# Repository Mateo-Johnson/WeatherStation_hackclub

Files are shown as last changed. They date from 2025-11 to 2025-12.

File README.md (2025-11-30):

# ESP32-C6 All-Inclusive Weather Station

A comprehensive environmental monitoring system designed for autonomous outdoor deployment. This weather station integrates meteorological sensors, air quality monitoring, GPS tracking, and solar power management into a single robust PCB design.

Screenshot 2025-11-29 at 9 49 39 PM
Screenshot 2025-11-29 at 9 50 54 PM
Screenshot 2025-11-29 at 9 50 24 PM
Screenshot 2025-11-29 at 9 52 07 PM

---

## Features

- **Microcontroller:** ESP32-C6-MINI (Wi-Fi 6, Bluetooth 5.2, low-power deep sleep)
- **Environmental Sensors:**
  - BME680: Temperature, Humidity, Pressure, VOC
  - SHT4x: Temperature and Humidity
  - SCD41: CO2, Temperature, Humidity
  - TSL25911: Ambient Light
- **GPS Module:** NEO-M8N with external U.FL antenna
- **Air Quality & Power Monitoring:**
  - Battery voltage, charge state, solar charging support
  - AQI estimation
- **Storage:** MicroSD card (DM3D-SF)
- **Connectivity:** Wi-Fi (primary), LoRa (fallback)
- **Power Management:** Deep sleep with peripheral power gating
- **Security:** TLS for Wi-Fi communications, optional HMAC payload signatures, secure key storage in NVS
- **Optional LEDs:** WS2812B RGB for status indicators

---

## Architecture

The firmware uses an RTOS-based task structure:

| Task | Priority | Description |
|---|---|---|
| SensorTask | High | Wake peripherals, read sensors, push measurements to queues |
| CommsTask | High | Wi-Fi/MQTT/HTTP upload, fallback SD logging, LoRa backup |
| StorageTask | Medium | Buffered SD writes, CRC/JSON formatting |
| PowerManagerTask | Highest  | Sensor power control, deep sleep, battery monitoring |
| WatchdogTask | Low | Detects stuck tasks or I²C bus lock and resets if necessary |

---

## Data Model

```json
{
  "device_id":"mjohnson-weather-v1",
  "timestamp":"2025-11-28T12:52:24Z",
  "sensors": {
    "bme680": {"temp_c": 23.54, "hum_pct": 45.2, "press_hpa": 1013.2, "gas_ohms": 120},
    "sht4x": {"temp_c": 23.50, "hum_pct": 45.1},
    "scd41": {"co2_ppm": 420, "temp_c": 23.4, "rh": 45.0},
    "tsl25911": {"lux": 3200},
    "gps": {"lat": 40.123456, "lon": -73.123456, "fix": true, "hdop": 0.9},
    "battery": {"voltage": 7.40, "charge_pct": 85, "charging": true},
    "aqi_est": 35
  },
  "signature": "xxxxx"  // CRC-8 checksum
}

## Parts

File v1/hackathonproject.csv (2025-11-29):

Reference | Qty | Value | DNP | Exclude from BOM | Exclude from Board | Footprint | Datasheet
BT1 | 1 | Battery_Cell |  |  |  | Battery:BatteryHolder_Keystone_3000_1x12mm | ~
C1,C2,C3,C4,C5,C6,C10,C12,C13,C15,C16,C17,C18,C19,C20 | 15 | 100nF |  |  |  | 10uF:C0402 | ~
C7,C9 | 2 | 10uF |  |  |  | 10uF:C0402 | ~
C8 | 1 | 22uF |  |  |  | 10uF:C0402 | ~
C11 | 1 | 4.7u |  |  |  | RP2350_80QFN_minimal:C_0402_1005Metric_small_pads | ~
C14 | 1 | 470nF |  |  |  | Capacitor_SMD:C_0402_1005Metric | ~
Card1 | 1 | DM3D-SF |  |  |  | DM3D:TF-SMD_DM3D-SF
D1,D2,D3 | 3 | LTST-C150RKT |  |  |  | LED_SMD:LED_1206_3216Metric | ~
D4,D5,D6 | 3 | WS2812B |  |  |  | LED_SMD:LED_WS2812B_PLCC4_5.0x5.0mm_P3.2mm | https://cdn-shop.adafruit.com/datasheets/WS2812B.pdf
J1 | 1 | USB_C_Receptacle_USB2.0_16P |  |  |  | Connector_USB:USB_C_Receptacle_HCTL_HC-TYPE-C-16P-01A | https://www.usb.org/sites/default/files/documents/usb_type-c.zip
J2 | 1 | Conn_02x05_Odd_Even |  |  |  | Connector_PinHeader_2.54mm:PinHeader_2x05_P2.54mm_Vertical | ~
J3 | 1 | U.FL-R-SMT(10) |  |  |  | Connector_Coaxial:U.FL_Hirose_U.FL-R-SMT-1_Vertical | ~
J4 | 1 | Conn_01x03_Pin |  |  |  | Connector_PinHeader_2.54mm:PinHeader_1x03_P2.54mm_Vertical | ~
J5 | 1 | Conn_01x02_Pin |  |  |  | Connector_JST:JST_PH_S2B-PH-K_1x02_P2.00mm_Horizontal | ~
R1,R2,R3,R5,R6,R7,R10,R11,R12 | 9 | RC0402FR-075K1L (5.1kΩ) |  |  |  | 0402:R0402 | ~
R4,R8,R9 | 3 | RC0402FR-13220RL (220Ω) |  |  |  | 0402:R0402 | ~
R13,R14 | 2 | 10k |  |  |  | 0402:R0402 | ~
SW1,SW2 | 2 | SKRKAGE020 |  |  |  | Button_Switch_SMD:SW_Push_SPST_NO_Alps_SKRK | ~
U1 | 1 | ESP32-C6-MINI-1 |  |  |  | RF_Module:ESP32-C6-MINI-1 | https://www.espressif.com/sites/default/files/documentation/esp32-c6-mini-1_mini-1u_datasheet_en.pdf
U2 | 1 | CH340N |  |  |  | Package_SO:SOP-8_3.9x4.9mm_P1.27mm | https://aitendo3.sakura.ne.jp/aitendo_data/product_img/ic/inteface/CH340N/ch340n.pdf
U3 | 1 | NEO-M8N |  |  |  | RF_GPS:ublox_NEO | https://content.u-blox.com/sites/default/files/NEO-M8-FW3_DataSheet_UBX-15031086.pdf
U4 | 1 | NCP1117-3.3_SOT223 |  |  |  | Package_TO_SOT_SMD:SOT-223-3_TabPin2 | http://www.onsemi.com/pub_link/Collateral/NCP1117-D.PDF
U5 | 1 | DS3231MZ |  |  |  | Package_SO:SOIC-8_3.9x4.9mm_P1.27mm | http://datasheets.maximintegrated.com/en/ds/DS3231M.pdf
U6 | 1 | BME680 |  |  |  | Package_LGA:Bosch_LGA-8_3x3mm_P0.8mm_ClockwisePinNumbering | https://ae-bst.resource.bosch.com/media/_tech/media/datasheets/BST-BME680-DS001.pdf
U7 | 1 | MP2607DL-LF-Z |  |  |  | MP2607DL:MP2607DL
U8 | 1 | SHT4x |  |  |  | Sensor_Humidity:Sensirion_DFN-4_1.5x1.5mm_P0.8mm_SHT4x_NoCentralPad | https://sensirion.com/media/documents/33FD6951/624C4357/Datasheet_SHT4x.pdf
U9 | 1 | SCD41-D-R2 |  |  |  | Sensor:Sensirion_SCD4x-1EP_10.1x10.1mm_P1.25mm_EP4.8x4.8mm | https://sensirion.com/media/documents/E0F04247/631EF271/CD_DS_SCD40_SCD41_Datasheet_D1.pdf
U10 | 1 | TCA9548AMRGER |  |  |  | Package_DFN_QFN:Texas_RGE0024C_VQFN-24-1EP_4x4mm_P0.5mm_EP2.1x2.1mm | http://www.ti.com/lit/ds/symlink/tca9548a.pdf
U11 | 1 | TSL25911FN |  |  |  | OptoDevice:AMS_TSL25911FN | https://ams.com/documents/20143/9331680/TSL2591_DS000338_7-00.pdf

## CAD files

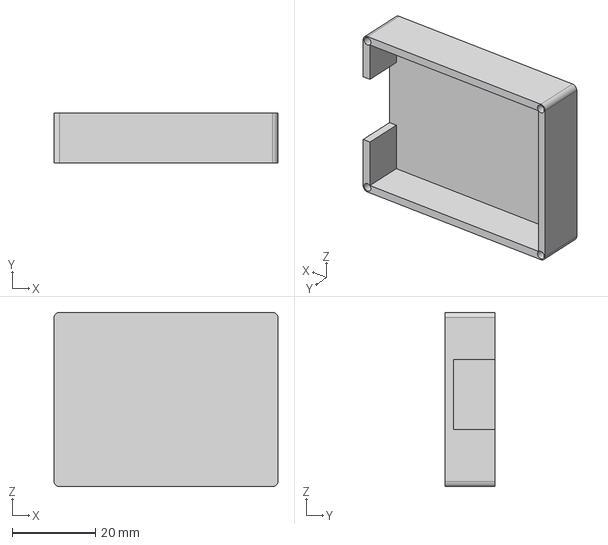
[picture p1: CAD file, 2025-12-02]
v1/case_bottom.step
53.9 x 12.0 x 41.9 mm

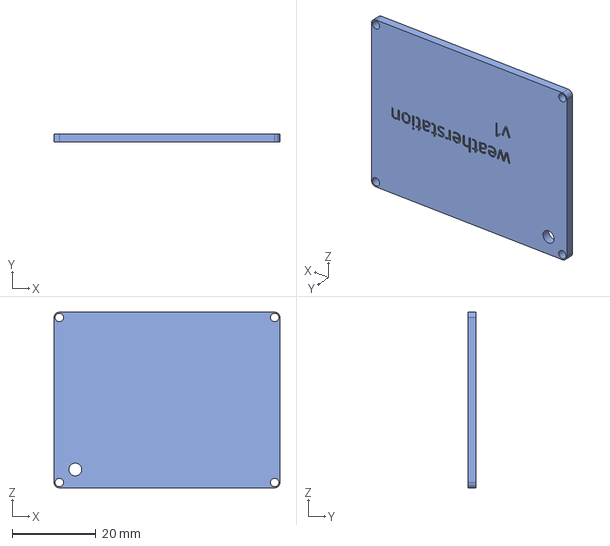
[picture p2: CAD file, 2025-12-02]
v1/case_top.step
53.9 x 2.00 x 41.9 mm

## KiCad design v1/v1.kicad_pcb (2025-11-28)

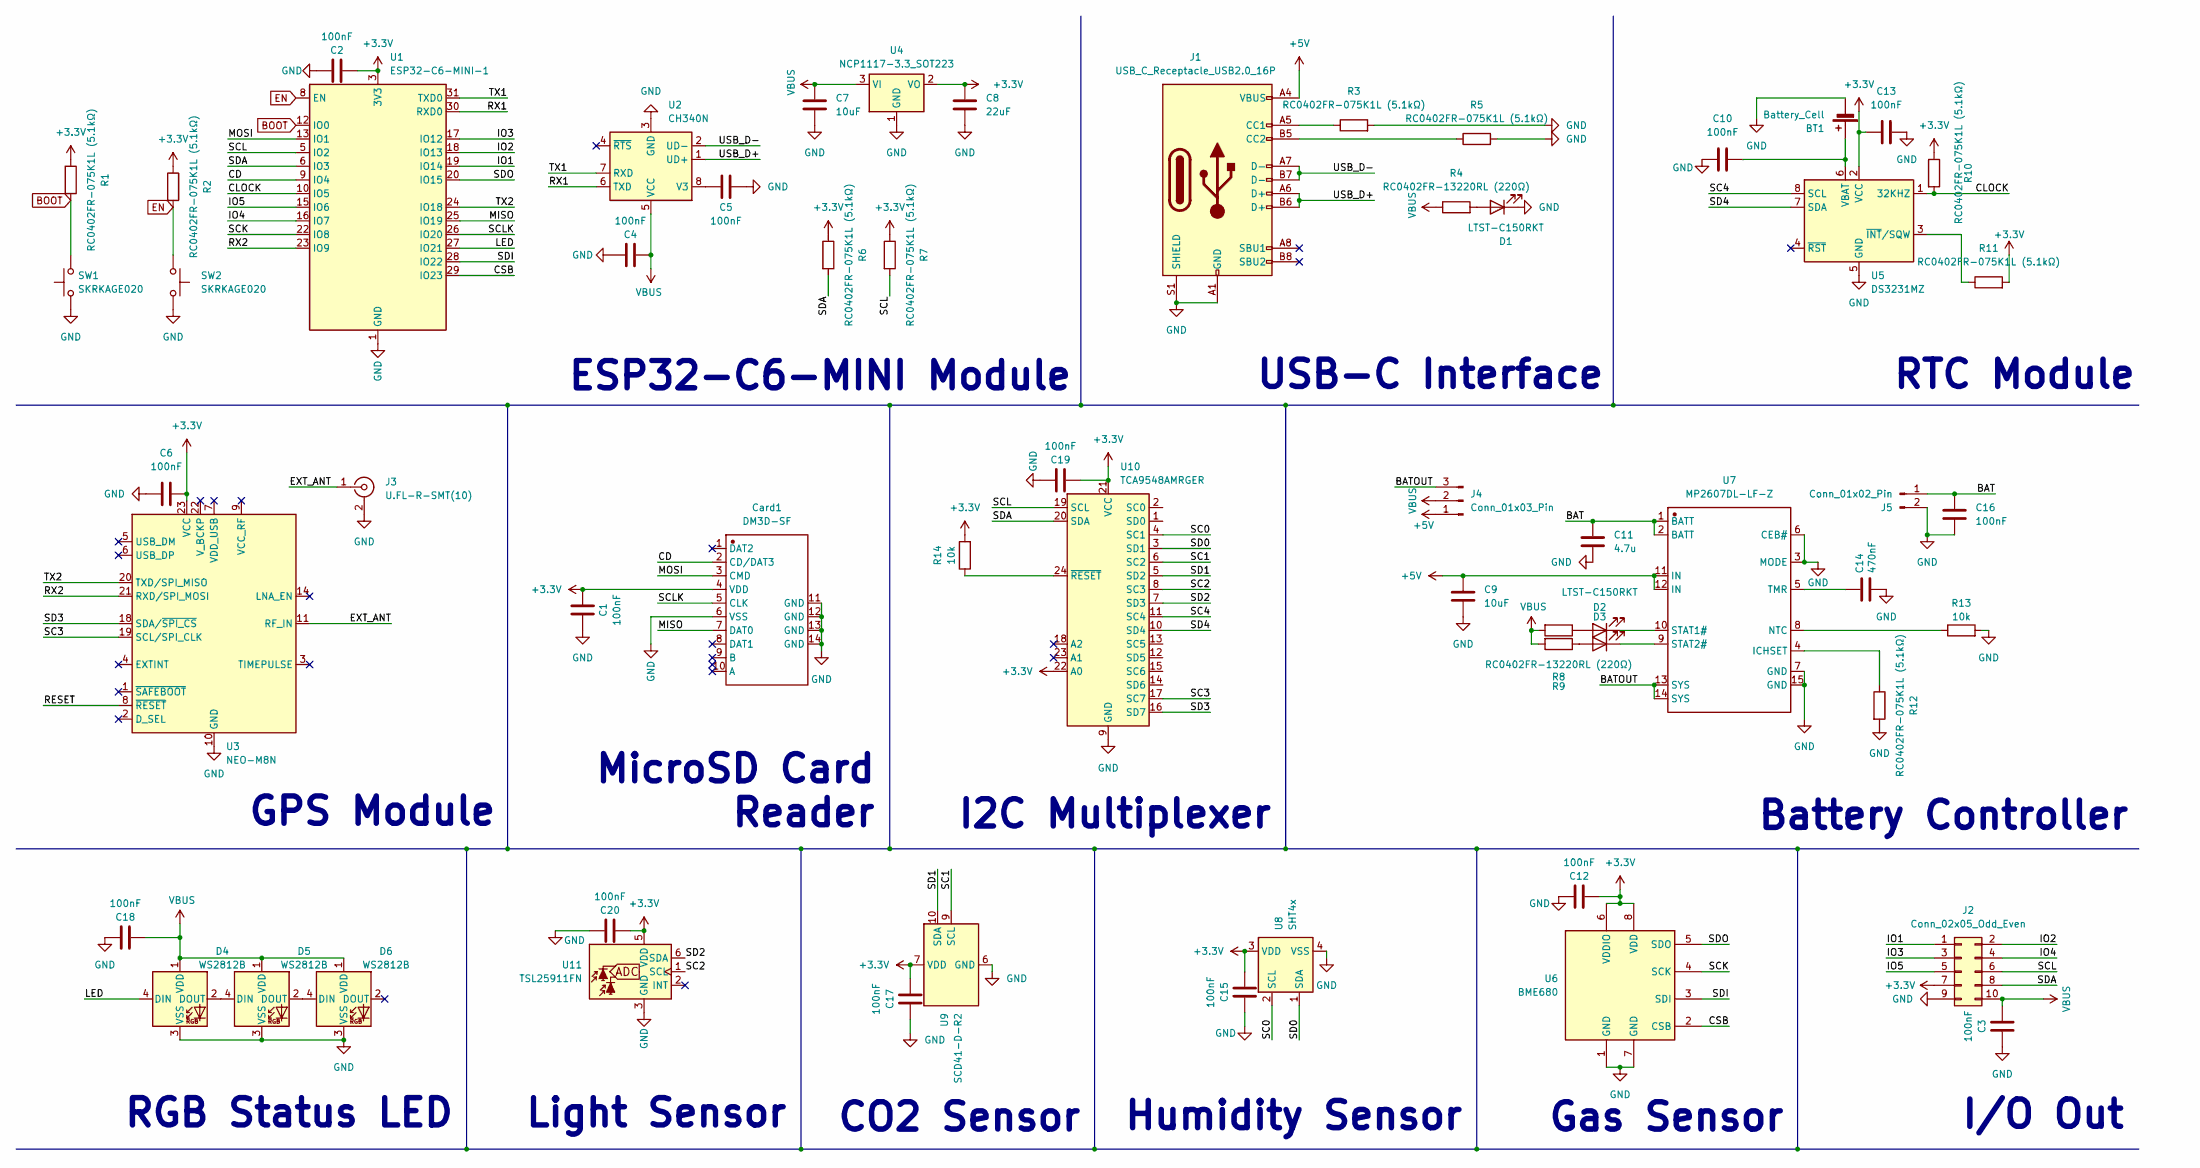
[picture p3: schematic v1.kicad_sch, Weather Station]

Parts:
BT1: Battery_Cell; BatteryHolder_Keystone_3000_1x12mm
C1, C2, C3, C4, C5, C6, C10, C12, C13, C15, C16, C17, C18, C19, C20: 100nF; C0402
C7, C9: 10uF; C0402
C8: 22uF; C0402
C11: 4.7u; C_0402_1005Metric_small_pads
C14: 470nF; C_0402_1005Metric
Card1: DM3D-SF; TF-SMD_DM3D-SF; Manufacturer Part DM3D-SF
D1, D2, D3: LTST-C150RKT; LED_1206_3216Metric
D4, D5, D6: WS2812B; LED_WS2812B_PLCC4_5.0x5.0mm_P3.2mm
J1: USB_C_Receptacle_USB2.0_16P; USB_C_Receptacle_HCTL_HC-TYPE-C-16P-01A
J2: Conn_02x05_Odd_Even; PinHeader_2x05_P2.54mm_Vertical
J3: U.FL-R-SMT(10); U.FL_Hirose_U.FL-R-SMT-1_Vertical
J4: Conn_01x03_Pin; PinHeader_1x03_P2.54mm_Vertical
J5: Conn_01x02_Pin; JST_PH_S2B-PH-K_1x02_P2.00mm_Horizontal
R1, R2, R3, R5, R6, R7, R10, R11, R12: RC0402FR-075K1L (5.1kΩ); R0402
R4, R8, R9: RC0402FR-13220RL (220Ω); R0402
R13, R14: 10k; R0402
SW1, SW2: SKRKAGE020; SW_Push_SPST_NO_Alps_SKRK
U1: ESP32-C6-MINI-1
U2: CH340N; SOP-8_3.9x4.9mm_P1.27mm
U3: NEO-M8N; ublox_NEO
U4: NCP1117-3.3_SOT223; SOT-223-3_TabPin2
U5: DS3231MZ; SOIC-8_3.9x4.9mm_P1.27mm
U6: BME680; Bosch_LGA-8_3x3mm_P0.8mm_ClockwisePinNumbering
U7: MP2607DL-LF-Z; MP2607DL; Manufacturer Part MP2607DL-LF-Z
U8: SHT4x; Sensirion_DFN-4_1.5x1.5mm_P0.8mm_SHT4x_NoCentralPad
U9: SCD41-D-R2; Sensirion_SCD4x-1EP_10.1x10.1mm_P1.25mm_EP4.8x4.8mm
U10: TCA9548AMRGER; Texas_RGE0024C_VQFN-24-1EP_4x4mm_P0.5mm_EP2.1x2.1mm
U11: TSL25911FN; AMS_TSL25911FN

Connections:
+3.3V: C1.1, C2.2, C6.2, C8.1, C12.2, C13.1, C15.2, C17.2, C19.2, C20.2, Card1.4 (VDD), J2.7, R1.1, R2.1, R6.1, R7.1, R10.1, R11.2, R14.2, U1.3 (3V3), U3.23 (VCC), U4.2 (VO), U5.2 (VCC), U6.6 (VDDIO), U6.8 (VDD), U8.3 (VDD), U9.7 (VDD), U9.19 (VDD), U10.21 (VCC), U10.22 (A0), U11.5 (VDD)
+5V: C9.1, J1.A4 (VBUS), J1.A9 (VBUS), J1.B4 (VBUS), J1.B9 (VBUS), J4.1, U7.11 (IN), U7.12 (IN)
/BAT: C11.1, C16.1, J5.1, U7.1 (BATT), U7.2 (BATT)
/BATOUT: J4.3, U7.13 (SYS), U7.14 (SYS)
/CD: Card1.2 (CD/DAT3), U1.9 (IO4)
/CLOCK: R10.2, U1.10 (IO5), U5.1 (32KHZ)
/CSB: U1.29 (IO23), U6.2 (CSB)
/EXT_ANT: J3.1 (In), U3.11 (RF_IN)
/IO1: J2.1, U1.19 (IO14)
/IO2: J2.2, U1.18 (IO13)
/IO3: J2.3, U1.17 (IO12)
/IO4: J2.4, U1.16 (IO7)
/IO5: J2.5, U1.15 (IO6)
/LED: D4.4 (DIN), U1.27 (IO21)
/MISO: Card1.7 (DAT0), U1.25 (IO19)
/MOSI: Card1.3 (CMD), U1.13 (IO1)
/RESET: U3.8 (~RESET)
/RX1: U1.30 (RXD0), U2.6 (TXD)
/RX2: U1.23 (IO9), U3.21 (RXD/SPI_MOSI)
/SC0: U8.2 (SCL), U10.4 (SC1)
/SC1: U9.9 (SCL), U10.6 (SC2)
/SC2: U10.8 (SC3), U11.1 (SCL)
/SC3: U3.19 (SCL/SPI_CLK), U10.17 (SC7)
/SC4: U5.8 (SCL), U10.11 (SC4)
/SCK: U1.22 (IO8), U6.4 (SCK)
/SCL: J2.6, R7.2, U1.5 (IO2), U10.19 (SCL)
/SCLK: Card1.5 (CLK), U1.26 (IO20)
/SD0: U8.1 (SDA), U10.3 (SD1)
/SD1: U9.10 (SDA), U10.5 (SD2)
/SD2: U10.7 (SD3), U11.6 (SDA)
/SD3: U3.18 (SDA/~SPI_CS), U10.16 (SD7)
/SD4: U5.7 (SDA), U10.10 (SD4)
/SDA: J2.8, R6.2, U1.6 (IO3), U10.20 (SDA)
/SDI: U1.28 (IO22), U6.3 (SDI)
/SDO: U1.20 (IO15), U6.5 (SDO)
/TX1: U1.31 (TXD0), U2.7 (RXD)
/TX2: U1.24 (IO18), U3.20 (TXD/SPI_MISO)
/USB_D+: J1.A6 (D+), J1.B6 (D+), U2.1 (UD+)
/USB_D-: J1.A7 (D-), J1.B7 (D-), U2.2 (UD-)
BOOT: R1.2, SW1.2, U1.12 (IO0)
EN: R2.2, SW2.1, U1.8 (EN)
GND: BT1.2 (-), C1.2, C2.1, C3.1, C4.1, C5.1, C6.1, C7.2, C8.2, C9.2, C10.2, C11.2, C12.1, C13.2, C14.2, C15.1, C16.2, C17.1, C18.1, C19.1, C20.1, Card1.6 (VSS), Card1.11 (GND), Card1.12 (GND), Card1.13 (GND), Card1.14 (GND), D1.1 (K), D4.3 (VSS), D5.3 (VSS), D6.3 (VSS), J1.A1 (GND), J1.A12 (GND), J1.B1 (GND), J1.B12 (GND), J1.S1 (SHIELD), J2.9, J3.2 (Ext), J5.2, R3.2, R5.2, R12.2, R13.2, SW1.1, SW2.2, U1.1 (GND), U1.2 (GND), U1.11 (GND), U1.14 (GND), U1.36 (GND), U1.37 (GND), U1.38 (GND), U1.39 (GND), U1.40 (GND), U1.41 (GND), U1.42 (GND), U1.43 (GND), U1.44 (GND), U1.45 (GND), U1.46 (GND), U1.47 (GND), U1.48 (GND), U1.49 (GND), U1.50 (GND), U1.51 (GND), U1.52 (GND), U1.53 (GND), U2.3 (GND), U3.10 (GND), U3.12 (GND), U3.13 (GND), U3.24 (GND), U4.1 (GND), U5.5 (GND), U6.1 (GND), U6.7 (GND), U7.3 (MODE), U7.6 (CEB#), U7.7 (GND), U7.15 (GND), U8.4 (VSS), U9.6 (GND), U9.20 (GND), U9.21 (GND), U10.9 (GND), U11.3 (GND)
unnamed: BT1.1 (+), C10.1, U5.6 (VBAT)
unnamed: D1.2 (A), R4.2
unnamed: D2.2 (A), R8.1
unnamed: D2.1 (K), U7.10 (STAT1#)
unnamed: D3.2 (A), R9.1
unnamed: D3.1 (K), U7.9 (STAT2#)
unnamed: D4.2 (DOUT), D5.4 (DIN)
unnamed: D5.2 (DOUT), D6.4 (DIN)
unnamed: J1.A5 (CC1), R3.1
unnamed: J1.B5 (CC2), R5.1
unnamed: C5.2, U2.8 (V3)
unnamed: R11.1, U5.3 (~INT/SQW)
unnamed: R12.1, U7.4 (ICHSET)
unnamed: R13.1, U7.8 (NTC)
unnamed: C14.1, U7.5 (TMR)
unnamed: R14.1, U10.24 (~RESET)
VBUS: C3.2, C4.2, C7.1, C18.2, D4.1 (VDD), D5.1 (VDD), D6.1 (VDD), J2.10, J4.2, R4.1, R8.2, R9.2, U2.5 (VCC), U4.3 (VI)

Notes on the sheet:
Light Sensor
Battery Controller
RGB Status LED
MicroSD Card Reader
CO2 Sensor
RTC Module
I/O Out
I2C Multiplexer
ESP32-C6-MINI Module
GPS Module
USB-C Interface
Gas Sensor
Humidity Sensor

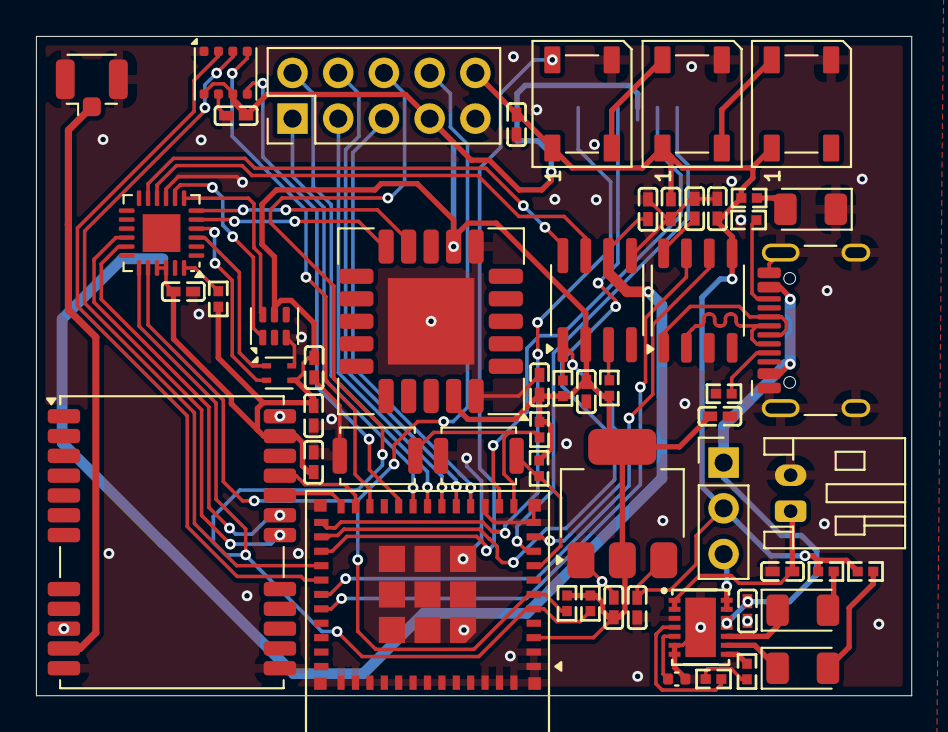
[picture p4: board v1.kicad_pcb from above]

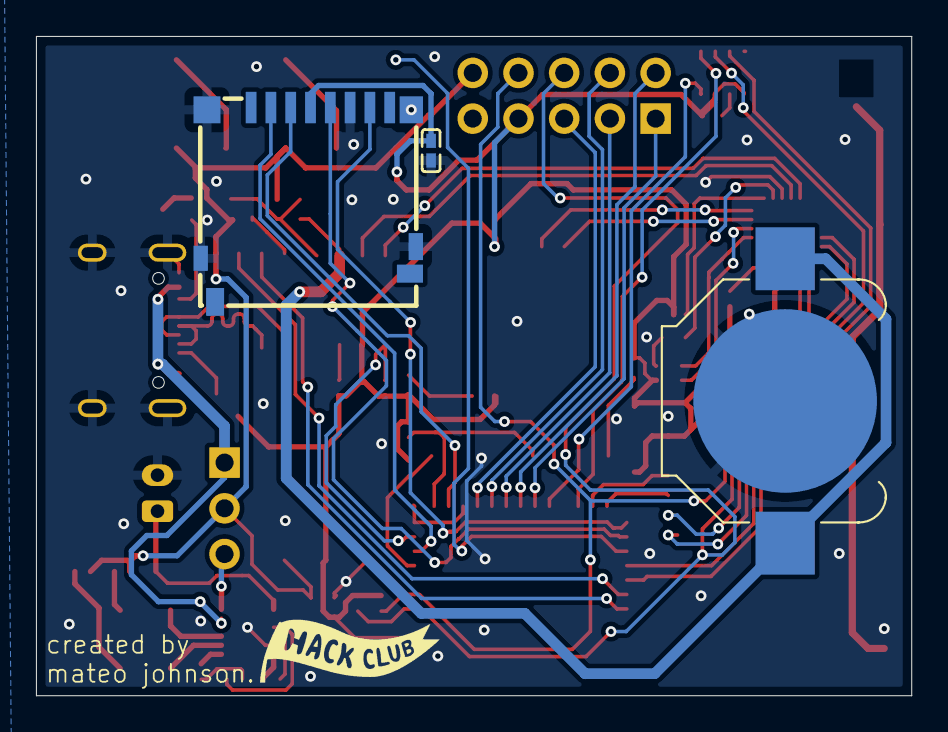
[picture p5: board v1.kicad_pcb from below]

Board: 2 copper layers, 48.6 x 36.6 mm, 59 parts (3 on the bottom side), 58 nets.

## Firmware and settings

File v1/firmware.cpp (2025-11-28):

// firmware_sample.cpp
// Full example C++ firmware skeleton for ESP32-C6 (ESP-IDF) + FreeRTOS.
// This is an implementation-ready sample skeleton demonstrating architecture,
// tasks, queues, recovery, I2C recovery, SD atomic writes, Wi-Fi -> HTTP fallback,
// LoRa fallback, power management and deep-sleep integration.
//
// NOT a drop-in production firmware: sensor drivers, real crypto, and OTA implementation
// must be filled with vendor libraries. This file demonstrates structure, error handling,
// and necessary safety patterns you asked for.
//
// Build with ESP-IDF C++ support. Link with mbedtls, fatfs, vfs, nvs_flash, esp_wifi, tcpip_adapter, etc.
// Keep this as a single-file starting point and extract to modules in real project.

#include <cstdio>
#include <cstring>
#include <cstdint>
#include <cstdlib>

extern "C" {
#include "freertos/FreeRTOS.h"
#include "freertos/task.h"
#include "freertos/queue.h"
#include "freertos/semphr.h"
#include "esp_system.h"
#include "esp_event.h"
#include "nvs_flash.h"
#include "esp_log.h"
#include "driver/i2c.h"
#include "driver/adc.h"
#include "esp_sleep.h"
#include "esp_vfs_fat.h"
#include "sdmmc_cmd.h"
#include "esp_wifi.h"
#include "esp_http_client.h"
#include "esp_ota_ops.h"
}

static const char *TAG = "weather-fw";

/////////////////////////////
// Configuration constants //
/////////////////////////////

static constexpr uint32_t SAMPLE_INTERVAL_SECONDS = 300;         // 5 minutes
static constexpr int MAX_RETRIES = 3;
static constexpr size_t SD_BUFFER_SIZE = 5120;                   // flush threshold
static constexpr int WIFI_CONNECT_TIMEOUT_MS = 10000;
static constexpr int LORA_TX_RETRY = 2;
static constexpr const char *DEVICE_ID = "mjohnson-weather-v1";
static constexpr int I2C_MASTER_PORT = I2C_NUM_0;
static constexpr int I2C_FREQ_HZ = 400000;
static constexpr gpio_num_t PIN_SENSOR_POWER = GPIO_NUM_21;      // example
static constexpr gpio_num_t PIN_GPS_POWER = GPIO_NUM_22;
static constexpr gpio_num_t PIN_LED_STATUS = GPIO_NUM_2;
static constexpr float BATTERY_CRITICAL_VOLTAGE = 6.5f;          // example for 2S Li-ion
static constexpr float BATTERY_LOW_WARNING_VOLTAGE = 7.0f;

///////////////////////////
// Data structures/types //
///////////////////////////

struct Bme680Sample { bool present; float temp_c; float hum_pct; float press_hpa; int gas_ohms; };
struct Sht4xSample { bool present; float temp_c; float hum_pct; };
struct Scd41Sample { bool present; int co2_ppm; float temp_c; float rh; };
struct Tsl25911Sample { bool present; float lux; };
struct GpsSample { bool present; double lat; double lon; bool fix; float hdop; uint64_t fix_age_s; };
struct BatterySample { float voltage; int pct; bool charging; };

struct Sample {
    char timestamp[32]; // ISO8601
    Bme680Sample bme680;
    Sht4xSample sht4x;
    Scd41Sample scd41;
    Tsl25911Sample tsl25911;
    GpsSample gps;
    BatterySample battery;
    int aqi_est;
    uint32_t crc8;
};

//////////////////////
// RTOS primitives  //
//////////////////////

static QueueHandle_t g_storage_queue = nullptr;   // Items: Sample*
static QueueHandle_t g_comms_queue = nullptr;     // Items: Sample*
static SemaphoreHandle_t g_i2c_mutex = nullptr;
static SemaphoreHandle_t g_sd_mutex = nullptr;
static TaskHandle_t g_watchdog_handle = nullptr;

//////////////////////////
// Helper / utilities   //
//////////////////////////

static uint32_t compute_crc8(const uint8_t *data, size_t len) {
    // simple CRC-8 (poly 0x07) for illustrative purposes
    uint8_t crc = 0;
    for (size_t i = 0; i < len; ++i) {
        crc ^= data[i];
        for (int b = 0; b < 8; ++b) {
            crc = (crc & 0x80) ? (uint8_t)((crc << 1) ^ 0x07) : (uint8_t)(crc << 1);
        }
    }
    return crc;
}

static void format_timestamp_iso8601(char *out, size_t out_sz) {
    // Attempt to read from RTC or system time.
    time_t now;
    time(&now);
    struct tm timeinfo;
    gmtime_r(&now, &timeinfo);
    strftime(out, out_sz, "%Y-%m-%dT%H:%M:%SZ", &timeinfo);
}

////////////////////////////
// Peripheral init stubs  //
////////////////////////////

static esp_err_t init_nvs_and_rtc() {
    esp_err_t err = nvs_flash_init();
    if (err == ESP_ERR_NVS_NO_FREE_PAGES || err == ESP_ERR_NVS_NEW_VERSION_FOUND) {
        ESP_ERROR_CHECK(nvs_flash_erase());
        err = nvs_flash_init();
    }
    if (err != ESP_OK) {
        ESP_LOGE(TAG, "NVS init failed: %d", err);
        return err;
    }
    // RTC assumed via DS3231 hardware; leave driver to implement. Here we verify system time plausibility.
    time_t now;
    time(&now);
    if (now < 1609459200) { // If before 2021-01-01 assume RTC unset
        ESP_LOGW(TAG, "System time not set; will sync later.");
    }
    return ESP_OK;
}

static esp_err_t init_i2c_bus() {
    // Strict initialization order and bus recovery enabled.
    i2c_config_t conf{};
    conf.mode = I2C_MODE_MASTER;
    conf.sda_io_num = (gpio_num_t)18;
    conf.scl_io_num = (gpio_num_t)19;
    conf.sda_pullup_en = GPIO_PULLUP_ENABLE;
    conf.scl_pullup_en = GPIO_PULLUP_ENABLE;
    conf.master.clk_speed = I2C_FREQ_HZ;
    esp_err_t err = i2c_param_config(I2C_MASTER_PORT, &conf);
    if (err != ESP_OK) return err;
    err = i2c_driver_install(I2C_MASTER_PORT, conf.mode, 0, 0, 0);
    if (err != ESP_OK) {
        ESP_LOGE(TAG, "i2c_driver_install failed: %d", err);
        return err;
    }
    return ESP_OK;
}

static void i2c_bus_recover() {
    // Attempt to recover stuck I2C bus: toggle SCL pulses and generate STOP.
    ESP_LOGW(TAG, "Attempting I2C bus recovery...");
    // Implementation depends on pin muxing; simplified here: re-init driver
    i2c_driver_delete(I2C_MASTER_PORT);
    vTaskDelay(pdMS_TO_TICKS(50));
    init_i2c_bus();
    ESP_LOGW(TAG, "I2C re-init attempted.");
}

//////////////////////////
// SD card (atomic append)
//////////////////////////

static const char *SD_MOUNT_POINT = "/sdcard";
static bool sd_mounted = false;

static esp_err_t init_sdcard() {
    esp_err_t ret;
    sdmmc_card_t *card = nullptr;
    esp_vfs_fat_sdmmc_mount_config_t mount_cfg = {
        .format_if_mount_failed = false,
        .max_files = 4,
    };
    // Default to 1-line SDMMC host or SPI host depending on hardware.
    ret = esp_vfs_fat_sdcard_mount(SD_MOUNT_POINT, nullptr, &mount_cfg, &card);
    if (ret == ESP_OK) {
        sd_mounted = true;
        ESP_LOGI(TAG, "SD card mounted at %s", SD_MOUNT_POINT);
        return ESP_OK;
    } else {
        ESP_LOGW(TAG, "Failed to mount SD card (%d). Will retry later.", ret);
        return ret;
    }
}

// Atomic append pattern: write to temp file, fsync, rename to target (append by opening, writing, fsync)
static bool sd_atomic_append_line(const char *filename, const char *line) {
    if (!sd_mounted) return false;
    if (xSemaphoreTake(g_sd_mutex, pdMS_TO_TICKS(2000)) != pdTRUE) {
        ESP_LOGW(TAG, "SD mutex busy");
        return false;
    }
    bool ok = false;
    char tmpname[256];
    snprintf(tmpname, sizeof(tmpname), "%s.tmp", filename);
    FILE *f = fopen(tmpname, "w");
    if (!f) {
        ESP_LOGE(TAG, "Failed to open tmp file for SD append");
        goto cleanup;
    }
    if (fprintf(f, "%s\n", line) < 0) goto cleanup_close;
    fflush(f);
    fsync(fileno(f));
    fclose(f);
    f = nullptr;

    // Append tmp to final file atomically by reopening final and appending then removing tmp.
    FILE *final = fopen(filename, "a");
    if (!final) {
        ESP_LOGE(TAG, "Failed to open final SD file for append");
        goto cleanup;
    }
    FILE *tmp = fopen(tmpname, "r");
    if (!tmp) {
        fclose(final);
        goto cleanup;
    }
    char buf[512];
    size_t r;
    while ((r = fread(buf, 1, sizeof(buf), tmp)) > 0) {
        if (fwrite(buf, 1, r, final) != r) {
            fclose(tmp); fclose(final);
            goto cleanup;
        }
    }
    fflush(final);
    fsync(fileno(final));
    fclose(tmp);
    fclose(final);
    remove(tmpname);
    ok = true;
    goto cleanup;

cleanup_close:
    if (f) fclose(f);
cleanup:
    xSemaphoreGive(g_sd_mutex);
    return ok;
}

//////////////////////
// Wi-Fi / HTTP stub //
//////////////////////

static bool wifi_connect_blocking() {
    // Implement a blocking connect with timeout. Here we stub successful connection.
    // In production, start Wi-Fi, wait for IP event or timeout.
    ESP_LOGI(TAG, "Connecting Wi-Fi (stub)...");
    vTaskDelay(pdMS_TO_TICKS(2000)); // simulate
    // return false to simulate offline during testing; return true if connected.
    return true;
}

static bool http_post_json(const char *url, const char *json_payload) {
    // Simplified synchronous HTTP POST. In production use esp_http_client APIs and proper TLS config.
    ESP_LOGI(TAG, "HTTP POST to %s - payload len %d", url, (int)strlen(json_payload));
    vTaskDelay(pdMS_TO_TICKS(300)); // simulate network latency
    // Simulate success
    return true;
}

//////////////////
// LoRa stub    //
//////////////////

static bool lora_send_binary(const uint8_t *data, size_t len) {
    // Stub LoRa transmission via SPI to module; handle ack etc. Return true on success.
    ESP_LOGI(TAG, "LoRa send %zu bytes (stub)", len);
    vTaskDelay(pdMS_TO_TICKS(100));
    return true;
}

//////////////////////////
// Sensor driver stubs  //
//////////////////////////

static Bme680Sample read_bme680() {
    Bme680Sample s{};
    s.present = true;
    s.temp_c = 21.5f + (esp_random() % 100) / 100.0f;
    s.hum_pct = 40.0f + (esp_random() % 100) / 100.0f;
    s.press_hpa = 1013.0f;
    s.gas_ohms = 120;
    return s;
}

static Sht4xSample read_sht4x() {
    Sht4xSample s{};
    s.present = true;
    s.temp_c = 21.6f;
    s.hum_pct = 40.1f;
    return s;
}

static Scd41Sample read_scd41() {
    Scd41Sample s{};
    s.present = true;
    s.co2_ppm = 420 + (esp_random() % 50);
    s.temp_c = 21.4f;
    s.rh = 40.2f;
    return s;
}

static Tsl25911Sample read_tsl25911() {
    Tsl25911Sample s{};
    s.present = true;
    s.lux = 1200.0f;
    return s;
}

static GpsSample read_gps() {
    GpsSample s{};
    s.present = true;
    s.fix = true;
    s.lat = 40.0 + (esp_random() % 1000)/10000.0;
    s.lon = -73.0 - (esp_random() % 1000)/10000.0;
    s.hdop = 0.9f;
    s.fix_age_s = 10;
    return s;
}

static BatterySample sample_battery_adc() {
    BatterySample b{};
    b.voltage = 7.40f; // stub
    b.pct = 85;
    b.charging = true;
    return b;
}

/////////////////////////
// Validation & utils  //
/////////////////////////

static void validate_and_sanitize_sample(Sample &s) {
    // Range checking and cross-sensor sanity rules
    if (s.bme680.present) {
        if (s.bme680.temp_c < -40 || s.bme680.temp_c > 85) s.bme680.present = false;
    }
    if (s.sht4x.present) {
        if (s.sht4x.temp_c < -40 || s.sht4x.temp_c > 125) s.sht4x.present = false;
    }
    // cross-check temp proximity
    if (s.bme680.present && s.sht4x.present) {
        float diff = fabsf(s.bme680.temp_c - s.sht4x.temp_c);
        if (diff > 5.0f) {
            // prefer SHT4x for humidity/temperature; mark BME if gross disagreement
            s.bme680.present = (diff <= 10.0f);
        }
    }
    // CO2 sanity
    if (s.scd41.present) {
        if (s.scd41.co2_ppm < 250 || s.scd41.co2_ppm > 5000) {
            s.scd41.present = false;
        }
    }
    // simple AQI estimate stub
    s.aqi_est = 0;
    if (s.bme680.present) {
        s.aqi_est = static_cast<int>(s.bme680.gas_ohms / 3);
    }
}

static void sample_to_json(const Sample &s, char *out, size_t out_sz) {
    // Minimal JSON serializer (no external deps). Ensure bounds.
    snprintf(out, out_sz,
        "{\"device_id\":\"%s\",\"timestamp\":\"%s\","
        "\"sensors\":{"
        "\"bme680\":{\"temp_c\":%.2f,\"hum_pct\":%.2f,\"press_hpa\":%.2f,\"gas_ohms\":%d},"
        "\"sht4x\":{\"temp_c\":%.2f,\"hum_pct\":%.2f},"
        "\"scd41\":{\"co2_ppm\":%d,\"temp_c\":%.2f,\"rh\":%.2f},"
        "\"tsl25911\":{\"lux\":%.1f},"
        "\"gps\":{\"lat\":%.6f,\"lon\":%.6f,\"fix\":%s,\"hdop\":%.2f},"
        "\"battery\":{\"voltage\":%.2f,\"pct\":%d,\"charging\":%s}"
        "},\"aqi_est\":%d,\"crc8\":%u}",
        DEVICE_ID,
        s.timestamp,
        s.bme680.temp_c, s.bme680.hum_pct, s.bme680.press_hpa, s.bme680.gas_ohms,
        s.sht4x.temp_c, s.sht4x.hum_pct,
        s.scd41.co2_ppm, s.scd41.temp_c, s.scd41.rh,
        s.tsl25911.lux,
        s.gps.lat, s.gps.lon, s.gps.fix ? "true" : "false", s.gps.hdop,
        s.battery.voltage, s.battery.pct, s.battery.charging ? "true" : "false",
        s.aqi_est, s.crc8
    );
}

//////////////////////////////
// Task implementations     //
//////////////////////////////

static void SensorTask(void *arg) {
    ESP_LOGI(TAG, "SensorTask started");
    while (true) {
        // Wait for wake signal or just run periodically if buried by timer
        // Here: loop-based with delay equivalent to wake policy, but real code will use event-driven wake
        // Boot-time gotcha: perform sensor presence probe once per boot and then per X cycles.
        // Power on sensors
        gpio_set_level(PIN_SENSOR_POWER, 1);
        vTaskDelay(pdMS_TO_TICKS(50)); // allow rails to stabilize

        Sample *sample = (Sample*)malloc(sizeof(Sample));
        if (!sample) {
            ESP_LOGE(TAG, "Out of memory for sample");
            vTaskDelay(pdMS_TO_TICKS(1000));
            continue;
        }
        memset(sample, 0, sizeof(Sample));
        format_timestamp_iso8601(sample->timestamp, sizeof(sample->timestamp));

        // Acquire I2C mutex for all sensor reads to avoid concurrency issues
        if (xSemaphoreTake(g_i2c_mutex, pdMS_TO_TICKS(2000)) != pdTRUE) {
            ESP_LOGW(TAG, "I2C busy, attempting recovery");
            i2c_bus_recover();
            xSemaphoreGive(g_i2c_mutex); // still give to avoid deadlock - safe only if taken
        }

        // Read sensors in safe order
        int tries = 0;
        do {
            sample->bme680 = read_bme680();
            if (sample->bme680.present) break;
            tries++;
            vTaskDelay(pdMS_TO_TICKS(10));
        } while (tries < MAX_RETRIES);

        sample->sht4x = read_sht4x();
        sample->scd41 = read_scd41();
        sample->tsl25911 = read_tsl25911();

        // GPS may be optional; power on only occasionally
        gpio_set_level(PIN_GPS_POWER, 1);
        vTaskDelay(pdMS_TO_TICKS(200)); // GPS warm-up (if hot)
        sample->gps = read_gps();
        gpio_set_level(PIN_GPS_POWER, 0);

        // battery sample
        sample->battery = sample_battery_adc();

        // Validate
        validate_and_sanitize_sample(*sample);

        // CRC over serialized core fields (simple)
        char json_buf[1024];
        sample_to_json(*sample, json_buf, sizeof(json_buf));
        sample->crc8 = compute_crc8((const uint8_t*)json_buf, strlen(json_buf));

        // Enqueue for storage and comms
        BaseType_t ok1 = xQueueSend(g_storage_queue, &sample, pdMS_TO_TICKS(1000));
        BaseType_t ok2 = xQueueSend(g_comms_queue, &sample, pdMS_TO_TICKS(1000));
        if (!(ok1 == pdTRUE && ok2 == pdTRUE)) {
            ESP_LOGW(TAG, "Queue overflow. Storage ok=%d comms ok=%d", ok1 == pdTRUE, ok2 == pdTRUE);
            // Backpressure strategy: prefer storage; if storage queue failed then drop oldest
            if (ok1 != pdTRUE) {
                Sample *dropped;
                xQueueReceive(g_storage_queue, &dropped, 0); // drop oldest
                free(dropped);
                xQueueSend(g_storage_queue, &sample, 0);
            }
            if (ok2 != pdTRUE) {
                // if comms queue is full, just rely on storage to persist sample
            }
        }

        // Turn off sensors
        gpio_set_level(PIN_SENSOR_POWER, 0);
        // Sleep until next sample or let power manager decide deep sleep
        for (int i=0;i< (SAMPLE_INTERVAL_SECONDS/10); ++i) {
            vTaskDelay(pdMS_TO_TICKS(10000));
        }
    }
}

static void StorageTask(void *arg) {
    ESP_LOGI(TAG, "StorageTask started");
    // Buffer to minimize writes
    char buffer[SD_BUFFER_SIZE];
    size_t buf_len = 0;
    for (;;) {
        Sample *sample = nullptr;
        if (xQueueReceive(g_storage_queue, &sample, pdMS_TO_TICKS(60000)) == pdTRUE) {
            if (!sample) continue;
            // Serialize
            char json_line[2048];
            sample_to_json(*sample, json_line, sizeof(json_line));
            // Append to buffer
            size_t line_len = strlen(json_line) + 1;
            if (buf_len + line_len >= sizeof(buffer)) {
                // Flush
                char filepath[256];
                format_timestamp_iso8601(json_line, sizeof(json_line)); // temp reuse, not ideal but ok
                // Use daily file name: /sdcard/YYYYMMDD.ndjson
                char dayname[16];
                time_t now; time(&now); struct tm tm; gmtime_r(&now, &tm);
                strftime(dayname, sizeof(dayname), "%Y%m%d", &tm);
                snprintf(filepath, sizeof(filepath), "%s/%s.ndjson", SD_MOUNT_POINT, dayname);
                sd_atomic_append_line(filepath, buffer);
                buf_len = 0;
            }
            // copy line into buffer (naive)
            if (line_len < sizeof(buffer) - buf_len) {
                memcpy(buffer + buf_len, json_line, line_len - 1);
                buffer[buf_len + line_len - 1] = '\n';
                buf_len += line_len;
            } else {
                // fallback: write directly
                char filepath[256];
                time_t now; time(&now); struct tm tm; gmtime_r(&now, &tm);
                char dayname[16]; strftime(dayname, sizeof(dayname), "%Y%m%d", &tm);
                snprintf(filepath, sizeof(filepath), "%s/%s.ndjson", SD_MOUNT_POINT, dayname);
                sd_atomic_append_line(filepath, json_line);
            }
            // mark sample persisted - in this simple example we don't track offsets, but you should store index!
            free(sample);
        } else {
            // timeout flush if buffer has pending data
            if (buf_len > 0) {
                char filepath[256];
                time_t now; time(&now); struct tm tm; gmtime_r(&now, &tm);
                char dayname[16]; strftime(dayname, sizeof(dayname), "%Y%m%d", &tm);
                snprintf(filepath, sizeof(filepath), "%s/%s.ndjson", SD_MOUNT_POINT, dayname);
                sd_atomic_append_line(filepath, buffer);
                buf_len = 0;
            }
        }
    }
}
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
extern "C" void app_main() {
    esp_log_level_set("*", ESP_LOG_INFO);
    ESP_LOGI(TAG, "Firmware skeleton starting");

    // Initialize NVS & RTC
    if (init_nvs_and_rtc() != ESP_OK) {
        ESP_LOGE(TAG, "NVS/RTC init failed - continuing but expect issues");
    }

    // Initialize GPIOs
    gpio_set_direction(PIN_SENSOR_POWER, GPIO_MODE_OUTPUT);
    gpio_set_direction(PIN_GPS_POWER, GPIO_MODE_OUTPUT);
    gpio_set_direction(PIN_LED_STATUS, GPIO_MODE_OUTPUT);
    gpio_set_level(PIN_SENSOR_POWER, 0);
    gpio_set_level(PIN_GPS_POWER, 0);
    gpio_set_level(PIN_LED_STATUS, 0);

    // Init mutexes and queues
    g_i2c_mutex = xSemaphoreCreateMutex();
    g_sd_mutex = xSemaphoreCreateMutex();
    g_storage_queue = xQueueCreate(64, sizeof(Sample*));
    g_comms_queue = xQueueCreate(64, sizeof(Sample*));
    if (!g_storage_queue || !g_comms_queue || !g_i2c_mutex || !g_sd_mutex) {
        ESP_LOGE(TAG, "Failed to create RTOS primitives");
        abort();
    }

    // Peripheral init in strict order
    if (init_i2c_bus() != ESP_OK) {
        ESP_LOGW(TAG, "I2C init failed, will attempt recovery during boot_recovery");
    }
    // SD init next (but non-fatal)
    init_sdcard();

    // Boot recovery
    boot_recovery_checks();

    // Start tasks (priorities: PowerManager highest)
    BaseType_t r;
    r = xTaskCreate(PowerManagerTask, "PowerMgr", 4096, nullptr, configMAX_PRIORITIES - 1, nullptr);
    r = xTaskCreate(WatchdogTask, "Watchdog", 3072, nullptr, 3, &g_watchdog_handle);
    r = xTaskCreate(StorageTask, "Storage", 8192, nullptr, 2, nullptr);
    r = xTaskCreate(CommsTask, "Comms", 8192, nullptr, 4, nullptr);
    r = xTaskCreate(SensorTask, "Sensor", 8192, nullptr, 5, nullptr);

    // Optionally schedule first deep sleep wakeup via RTC if enabling deep sleep mode
    // For demonstration we enable periodic timer wakeup to mimic solar-powered duty cycle.
    esp_sleep_enable_timer_wakeup((uint64_t)SAMPLE_INTERVAL_SECONDS * 1000000ULL);
    // Note: do NOT call esp_deep_sleep_start() here; SensorTask will call it when ready

    ESP_LOGI(TAG, "All tasks scheduled. Main will now idle.");
    // The main task can either delete itself or idle
    while (true) {
        vTaskDelay(pdMS_TO_TICKS(10000));
    }
}

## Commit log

2025-12-02 Add CAD link to README
2025-12-02 Add CAD document link to README
    Added a link to the CAD document for reference.
2025-12-02 Update CAD link to use markdown format
2025-12-02 Remove CAD document link from README because of forbidden error
    Removed a link to CAD document from the README.
